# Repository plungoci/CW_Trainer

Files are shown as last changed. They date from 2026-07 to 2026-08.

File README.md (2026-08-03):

# CW Trainer

[Română](#română) · [English](#english)

<p align="center">
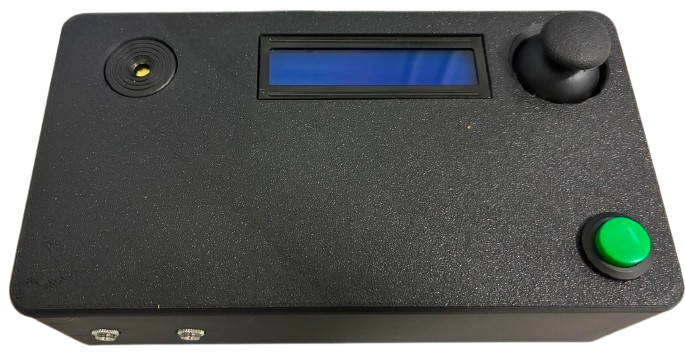
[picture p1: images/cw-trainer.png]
CW Trainer în carcasă
  
</p>

---

## Română

**CW Trainer** este un antrenor de cod Morse pentru Arduino Nano (ATmega328P).
Folosește un LCD I²C 16×2 și un buzzer activ pentru demonstrarea semnalelor,
iar pentru operare oferă butonul Morse existent, un joystick KY-023, o intrare
pentru cheie simplă și o mufă TRS pentru paddle.

### Funcții actuale

- Meniu neblocant pentru alegerea exercițiului și reglarea vitezei între **5 și
  50 WPM** (implicit 15 WPM).
- Trei tipuri de exerciții: **Litere** (`A`–`Z`), **Cifre** (`0`–`9`) și
  **Fraze** (`CQ CQ`, `TEST ONE`, `HELLO WORLD`, `73 DE YO6LPG`).
- Redare Morse fără `delay()` pentru demonstrație și paddle, cu temporizare
  standard: punct `1200 / WPM`, linie 3 puncte, spațiu între elemente 1 punct,
  între litere 3 puncte și între cuvinte 7 puncte.
- Feedback pe LCD pentru răspuns: ținta (`T:`), următorul semnal între `[]`,
  `GRESIT! Incearca`, `CORECT!` și expirarea timpului. `/` separă literele,
  iar `//` separă cuvintele.
- Cheia originală de pe D7 pornește antrenamentul din meniul principal și
  introduce puncte/linii în timpul răspunsului. O apăsare sub două unități de
  timp este punct; una mai lungă este linie.
- Cheie simplă cu sidetone imediat și keyer simplu pentru paddle. Când DIT și
  DAH sunt apăsate simultan, următorul element alternează; modurile iambic A/B
  și memoria paddlelor nu sunt implementate.

### Componente

| Cantitate | Componentă | Observații |
| ---: | --- | --- |
| 1 | Arduino Nano compatibil, ATmega328P, USB-C | Alimentare și control. |
| 1 | LCD 1602 I²C | Adresa implicită este `0x27`; încearcă `0x3F` dacă nu răspunde. |
| 1 | Buzzer piezoelectric activ | Conectat la D8 și GND. |
| 1 | Buton momentan normal deschis | Cheia Morse originală, conectată la D7 și GND. |
| 1 | Joystick KY-023 | Navigare în meniu și selectare. |
| 1 | Jack pentru cheie simplă | Semnal la D3, masă la GND. |
| 1 | Jack TRS pentru paddle | Tip = DIT, Ring = DAH, Sleeve = GND. |
| – | Fire, carcasă și elemente de fixare | După necesități. |

Toate intrările de cheie folosesc `INPUT_PULLUP`; fiecare contact se leagă la
GND când este apăsat. Nu este necesară o rezistență externă de pull-up.

### Conexiuni

| Semnal | Pin Nano | Configurație |
| --- | --- | --- |
| LCD VCC / GND | 5V / GND | Masă comună. |
| LCD SDA / SCL | A4 / A5 | Magistrala I²C. |
| Buzzer activ | D8 / GND | Ieșire digitală. |
| Buton / cheie existentă | D7 / GND | `INPUT_PULLUP`, activ LOW. |
| KY-023 axa verticală / orizontală | A0 / A1 | Intrări ADC pe 10 biți. |
| KY-023 SW | D2 | `INPUT_PULLUP`, activ LOW. |
| Cheie simplă | D3 / GND | `INPUT_PULLUP`, activ LOW. |
| Paddle DIT (Tip) | D5 | `INPUT_PULLUP`, activ LOW. |
| Paddle DAH (Ring) | D4 | `INPUT_PULLUP`, activ LOW. |
| Paddle masă (Sleeve) | GND |  |

Pentru montajul calibrat, A0 este sus la valori `>700` și jos la `<300`, iar
A1 este dreapta la `>700` și stânga la `<300`. Direcțiile pot diferi de
etichetele VRx/VRy ale joystickului; pragurile sunt centralizate în schiță.
Alimentează KY-023 la 5 V numai cu acest Nano de 5 V. Pentru o placă cu ADC de
3,3 V, folosește niveluri sigure pentru intrări.

### Utilizare

1. La pornire, LCD-ul afișează `CW Trainer` și `YO6LPG` timp de două secunde.
2. În meniul principal, mișcă joystickul **stânga/dreapta** între `Training`,
   `Viteza WPM`, `Start Training` și `Inapoi`. Apăsarea scurtă a lui SW
   confirmă elementul selectat.
3. În `Training`, alege Litere, Cifre sau Fraze și apasă scurt SW pentru a
   salva. O apăsare lungă SW revine fără salvare.
4. În `Viteza WPM`, dreapta crește și stânga scade WPM; sus/jos nu schimbă
   viteza. O apăsare scurtă sau lungă SW revine în meniu.
5. Alege `Start Training` sau apasă butonul D7 din meniul principal. Dispozitivul
   afișează ținta, redă codul, apoi așteaptă răspunsul pe D7. Dacă răspunsul nu
   începe în 10 secunde, runda expiră; după rezultat, următoarea rundă pornește
   automat după trei secunde.
6. O apăsare lungă SW în timpul antrenamentului oprește runda și revine în
   meniul principal.

<p align="center">
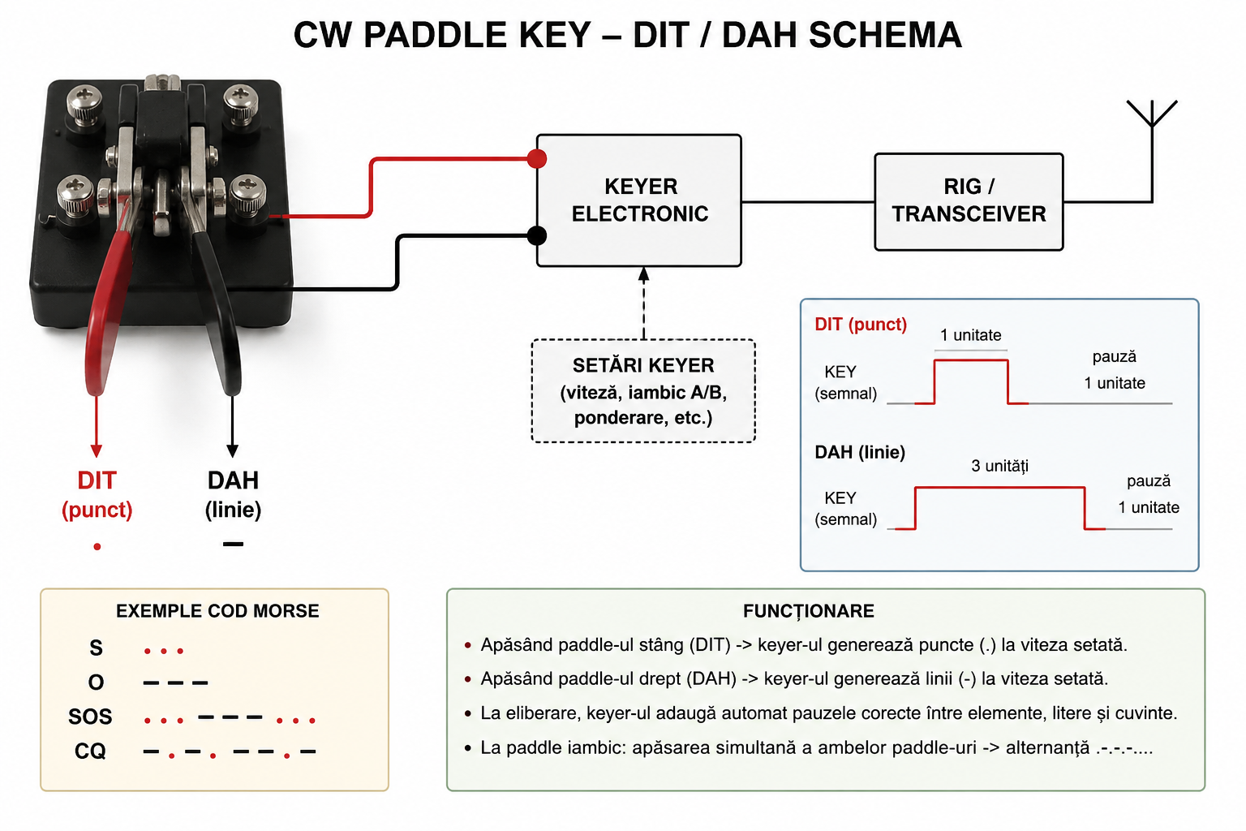
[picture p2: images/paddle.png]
Descriere paddle
   
</p>

### Instalare și diagnosticare

1. Instalează [Arduino IDE](https://www.arduino.cc/en/software) și biblioteca
   **LiquidCrystal I2C** din Library Manager. `Wire` este inclusă în IDE.
2. Deschide `cw_trainer.ino`, selectează placa Arduino Nano și portul serial,
   apoi compilează și încarcă schița.
3. Pentru calibrarea joystickului, deschide Serial Monitor la **115200 baud**
   în ecranul `Viteza WPM`. Schița imprimă valorile A0/A1, direcția detectată
   și WPM înainte/după fiecare comandă. După calibrare, setează
   `JOYSTICK_DIAGNOSTICS` la `false` dacă nu mai dorești mesaje seriale.

### Depanare

- **LCD gol:** verifică alimentarea, contrastul și încearcă adresa `0x3F`.
- **Direcții inversate:** verifică valorile din Serial Monitor și ajustează
  pragurile sau corespondența axelor din `directionFromJoystick()`.
- **Paddle inversat:** inversează valorile `PIN_PADDLE_DIT` și
  `PIN_PADDLE_DAH`.
- **Fără sunet:** verifică polaritatea buzzerului activ și legăturile D8/GND.

---

## English

**CW Trainer** is an Arduino Nano (ATmega328P) Morse-code trainer. A 16×2 I²C
LCD and active buzzer demonstrate the signals; the existing Morse button,
KY-023 joystick, straight-key input, and TRS paddle input provide operation.

### Current features

- Non-blocking menu; speed is adjustable from **5 to 50 WPM** (15 WPM by
  default).
- **Letters** (`A`–`Z`), **Numbers** (`0`–`9`), and **Phrases** (`CQ CQ`,
  `TEST ONE`, `HELLO WORLD`, `73 DE YO6LPG`) training modes.
- Delay-free Morse playback for demonstrations and paddle output, using
  standard timing derived from `1200 / WPM`.
- LCD answer feedback, including target display, highlighted next element,
  correct/incorrect messages, and timeout. `/` marks letters and `//` words.
- D7 remains the original active-low Morse button: it starts training from the
  main menu and records dots/dashes during an answer.
- Straight-key sidetone and a simple non-iambic paddle keyer. Simultaneous DIT
  and DAH alternate the next element; paddle memory and iambic A/B are not yet
  implemented.

### Wiring and use

The hardware mapping is D8 buzzer, D7 existing key, A0/A1 joystick axes, D2
joystick switch, D3 straight key, D4 paddle DIT, and D5 paddle DAH. All key
inputs use `INPUT_PULLUP` and are active LOW; connect their other contact to
GND. LCD I²C uses A4/SDA and A5/SCL. The full wiring table and Romanian
step-by-step operating guide above are the canonical reference.

Install **LiquidCrystal I2C** through Arduino IDE's Library Manager, open
`cw_trainer.ino`, select the Arduino Nano and serial port, then compile and
upload. If the display does not respond at `0x27`, try `0x3F`. For joystick
calibration, use Serial Monitor at **115200 baud** in the WPM screen; set
`JOYSTICK_DIAGNOSTICS` to `false` once calibration is complete.

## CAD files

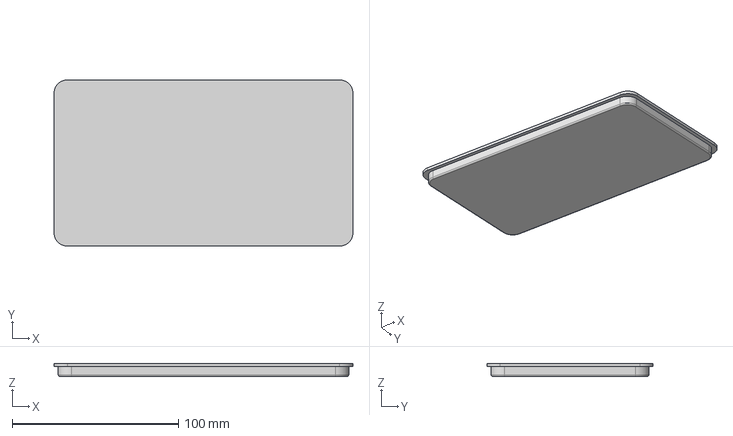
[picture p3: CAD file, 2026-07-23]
3D Model/CW-Trainer Lid.step
180.0 x 100.0 x 8.00 mm

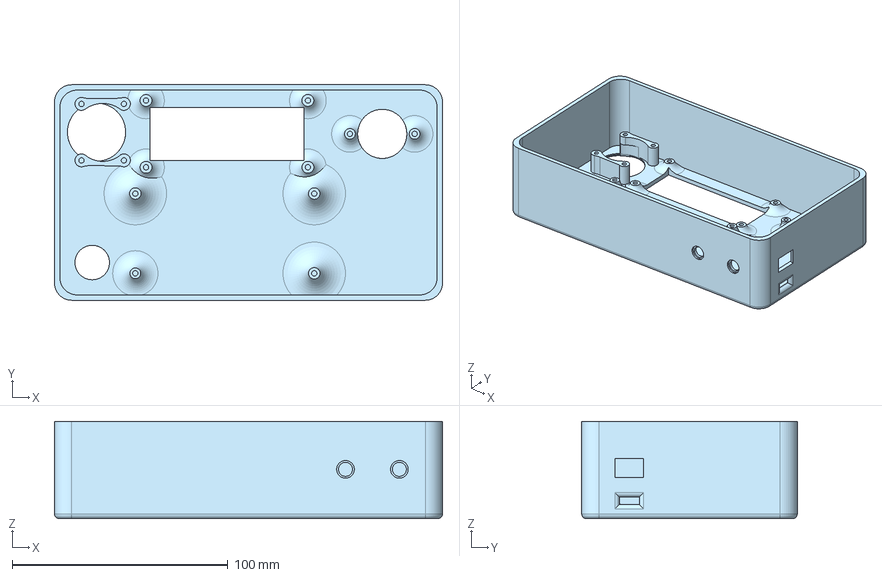
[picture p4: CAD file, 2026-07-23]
3D Model/CW-Trainer Box.step
180.0 x 100.0 x 45.0 mm

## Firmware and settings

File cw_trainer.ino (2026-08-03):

#include <Wire.h>
#include <LiquidCrystal_I2C.h>
#include <string.h>
#include <stdio.h>

// LCD 1602 I2C existent; incearca 0x3F daca modulul nu raspunde la 0x27.
LiquidCrystal_I2C lcd(0x27, 16, 2);

// Arduino Nano (ATmega328P): A4/A5 sunt rezervati pentru LCD/I2C, iar D8
// pentru buzzer. D7 este cheia/butonul original si nu este reutilizat.
constexpr byte buzzerPin = 8;
constexpr byte keyPin = 7;  // Buton existent, activ LOW, INPUT_PULLUP.
// Calibrarea pe dispozitiv a aratat ca orientarea fizica nu corespunde
// etichetelor VRx/VRy: A0 se modifica sus/jos, iar A1 stanga/dreapta.
constexpr byte PIN_JOYSTICK_AXIS_1 = A0;
constexpr byte PIN_JOYSTICK_AXIS_2 = A1;
constexpr byte PIN_JOYSTICK_SW = 2;
constexpr byte PIN_STRAIGHT_KEY = 3;
constexpr byte PIN_PADDLE_DIT = 5;
constexpr byte PIN_PADDLE_DAH = 4;

constexpr int DEFAULT_WPM = 15;
constexpr int MIN_WPM = 5;
constexpr int MAX_WPM = 50;
constexpr int WPM_STEP = 1;
constexpr byte MAIN_MENU_ITEM_COUNT = 5;
constexpr byte TEST_MENU_ITEM_COUNT = 2;
// Nano are ADC pe 10 biti (0..1023); aceste praguri sunt usor de calibrat.
constexpr int JOYSTICK_LOW_THRESHOLD = 300;
constexpr int JOYSTICK_HIGH_THRESHOLD = 700;
// Valorile brute verificate pentru montajul curent: A0 mare = SUS, A0 mic = JOS,
// A1 mare = DREAPTA si A1 mic = STANGA. Nu deduce directia din numele VRx/VRy.
constexpr bool JOYSTICK_DIAGNOSTICS = true;
constexpr unsigned long JOYSTICK_INITIAL_REPEAT_MS = 350;
constexpr unsigned long JOYSTICK_REPEAT_MS = 140;
constexpr unsigned long JOYSTICK_DEBOUNCE_MS = 25;
constexpr unsigned long JOYSTICK_LONG_PRESS_MS = 800;
constexpr unsigned long KEY_DEBOUNCE_MS = 12;
constexpr unsigned long answerTimeout = 10000UL;

struct MorseTiming {
  unsigned long dit;
  unsigned long dah;
  unsigned long elementGap;
  unsigned long characterGap;
  unsigned long wordGap;
};

enum class TrainingMode { Letters, Numbers, Phrases };
enum class AppState { MainMenu, TrainingSelection, WpmSettings, Training, TestMenu, KeyTest, PaddleTest };
enum class JoystickEvent { None, Up, Down, Left, Right, ShortPress, LongPress };
enum class OutputPhase { Idle, Tone, Gap };
enum class TrainingPhase { Choose, Preview, Playing, WaitAnswer, Result };

int currentWpm = DEFAULT_WPM;
MorseTiming timing;
TrainingMode trainingMode = TrainingMode::Letters;
AppState appState = AppState::MainMenu;
TrainingPhase trainingPhase = TrainingPhase::Choose;
byte menuIndex = 0;
byte selectionIndex = 0;
byte testMenuIndex = 0;
bool displayDirty = true;

// Buffer comun pentru ecranele de test hardware: acumuleaza simbolurile
// tastate pentru litera curenta si textul deja decodat. Titlul ecranului
// ramane fix pe randul de sus; randul de jos arata textul decodat urmat de
// codul Morse curent, neterminat, intre paranteze drepte.
constexpr byte TEST_KEYER_TEXT_CAP = 32;
char testKeyerCode[9];
byte testKeyerCodeLength = 0;
char testKeyerText[TEST_KEYER_TEXT_CAP + 1];
byte testKeyerTextLength = 0;
unsigned long testKeyerLastSymbolAt = 0;
bool testKeyerHasPendingSymbol = false;

bool previousKeyTestDown = false;
unsigned long keyTestChangedAt = 0;
unsigned long keyTestDownAt = 0;

bool previousPaddleTestDitDown = false;
unsigned long paddleTestDitChangedAt = 0;
bool previousPaddleTestDahDown = false;
unsigned long paddleTestDahChangedAt = 0;

const char characters[] = "ABCDEFGHIJKLMNOPQRSTUVWXYZ0123456789";
const char *const morseCodes[] = {
  ".-", "-...", "-.-.", "-..", ".", "..-.", "--.", "....", "..", ".---",
  "-.-", ".-..", "--", "-.", "---", ".--.", "--.-", ".-.", "...", "-",
  "..-", "...-", ".--", "-..-", "-.--", "--..",
  "-----", ".----", "..---", "...--", "....-", ".....", "-....", "--...", "---..", "----."
};
constexpr byte LETTER_COUNT = 26;
constexpr byte CHARACTER_COUNT = sizeof(characters) - 1;
// Frazele sunt stocate in flash ca date constante; extinde lista fara RAM dinamic.
const char phrases[][17] = { "CQ CQ", "TEST ONE", "HELLO WORLD", "73 DE YO6LPG" };
constexpr byte PHRASE_COUNT = sizeof(phrases) / sizeof(phrases[0]);

// Motorul comun pentru demonstratie si paddle. Nu foloseste delay().
OutputPhase outputPhase = OutputPhase::Idle;
const char *outputCode = nullptr;
byte outputPosition = 0;
unsigned long outputDeadline = 0;
bool outputFinished = false;

char targetText[17];
char targetCode[110];
bool answerStarted = false;
bool previousExistingKeyDown = false;
unsigned long existingKeyChangedAt = 0;
unsigned long existingKeyDownAt = 0;
unsigned long answerStartedAt = 0;
unsigned long phaseStartedAt = 0;
bool answerCorrect = false;

void acceptAnswerSignal(char signal);
// Pozitia urmatorului semnal care trebuie introdus. Separatorii din targetCode
// ('/' intre litere si '|' intre cuvinte) nu necesita o apasare a cheii.
byte expectedPosition = 0;
bool answerHasError = false;
unsigned long answerErrorShownAt = 0;

bool previousStraightDown = false;
unsigned long straightChangedAt = 0;
bool paddleLastWasDit = false;

bool previousPaddleDitDown = false;
unsigned long paddleDitChangedAt = 0;
bool previousPaddleDahDown = false;
unsigned long paddleDahChangedAt = 0;

bool previousJoystickButtonDown = false;
unsigned long joystickButtonChangedAt = 0;
unsigned long joystickButtonDownAt = 0;
bool joystickLongReported = false;
JoystickEvent heldDirection = JoystickEvent::None;
unsigned long directionChangedAt = 0;
unsigned long directionRepeatAt = 0;
int lastJoystickAxis1 = 0;
int lastJoystickAxis2 = 0;

void recalculateMorseTiming() {
  timing.dit = 1200UL / currentWpm;
  timing.dah = timing.dit * 3UL;
  timing.elementGap = timing.dit;
  timing.characterGap = timing.dit * 3UL;
  timing.wordGap = timing.dit * 7UL;
}

const char *modeName(TrainingMode mode) {
  if (mode == TrainingMode::Letters) return "Litere";
  if (mode == TrainingMode::Numbers) return "Cifre";
  return "Fraze";
}

void soundOn() { digitalWrite(buzzerPin, HIGH); }
void soundOff() { digitalWrite(buzzerPin, LOW); }

void startMorseOutput(const char *code) {
  outputCode = code;
  outputPosition = 0;
  outputPhase = OutputPhase::Idle;
  outputFinished = false;
}

bool morseOutputBusy() { return outputCode != nullptr; }

void updateMorseOutput() {
  if (!outputCode) return;
  unsigned long now = millis();
  if (outputPhase == OutputPhase::Idle) {
    if (outputCode[outputPosition] == '\0') {
      outputCode = nullptr;
      outputFinished = true;
      soundOff();
      return;
    }
    // Separators are generated by buildPhraseMorse(): the normal element gap
    // has already elapsed, so add the remaining units for a character/word.
    if (outputCode[outputPosition] == '/' || outputCode[outputPosition] == '|') {
      soundOff();
      outputDeadline = now + (outputCode[outputPosition] == '/' ?
        timing.characterGap - timing.elementGap : timing.wordGap - timing.elementGap);
      outputPhase = OutputPhase::Gap;
      return;
    }
    soundOn();
    outputDeadline = now + (outputCode[outputPosition] == '.' ? timing.dit : timing.dah);
    outputPhase = OutputPhase::Tone;
  } else if (now >= outputDeadline) {
    if (outputPhase == OutputPhase::Tone) {
      soundOff();
      outputDeadline = now + timing.elementGap;
      outputPhase = OutputPhase::Gap;
    } else {
      ++outputPosition;
      outputPhase = OutputPhase::Idle;
    }
  }
}

const char *morseForCharacter(char character) {
  if (character >= 'A' && character <= 'Z') return morseCodes[character - 'A'];
  if (character >= '0' && character <= '9') return morseCodes[LETTER_COUNT + character - '0'];
  return nullptr;
}

void buildPhraseMorse(const char *phrase, char *destination, size_t destinationSize) {
  size_t used = 0;
  for (byte i = 0; phrase[i] != '\0' && used + 1 < destinationSize; ++i) {
    if (phrase[i] == ' ') {
      destination[used++] = '|';
      continue;
    }
    const char *code = morseForCharacter(phrase[i]);
    if (!code) continue;
    for (byte j = 0; code[j] != '\0' && used + 1 < destinationSize; ++j) destination[used++] = code[j];
    if (phrase[i + 1] != '\0' && phrase[i + 1] != ' ' && used + 1 < destinationSize) destination[used++] = '/';
  }
  destination[used] = '\0';
}

JoystickEvent directionFromJoystick() {
  // Citeste ambele canale o singura data, pentru ca diagnosticul si decodorul
  // sa descrie exact aceeasi pozitie a manetei.
  lastJoystickAxis1 = analogRead(PIN_JOYSTICK_AXIS_1);
  lastJoystickAxis2 = analogRead(PIN_JOYSTICK_AXIS_2);

  // A0 este axa fizica verticala in acest montaj; ea nu ajunge la adjustWpm().
  if (lastJoystickAxis1 > JOYSTICK_HIGH_THRESHOLD) return JoystickEvent::Up;
  if (lastJoystickAxis1 < JOYSTICK_LOW_THRESHOLD) return JoystickEvent::Down;
  // A1 este axa fizica orizontala. Valoarea mare este dreapta fizica.
  if (lastJoystickAxis2 < JOYSTICK_LOW_THRESHOLD) return JoystickEvent::Left;
  if (lastJoystickAxis2 > JOYSTICK_HIGH_THRESHOLD) return JoystickEvent::Right;
  return JoystickEvent::None;
}

const char *joystickEventName(JoystickEvent event) {
  switch (event) {
    case JoystickEvent::Up: return "UP";
    case JoystickEvent::Down: return "DOWN";
    case JoystickEvent::Left: return "LEFT";
    case JoystickEvent::Right: return "RIGHT";
    default: return "NONE";
  }
}

void logWpmJoystickDiagnostic(JoystickEvent event, int wpmBefore, int wpmAfter) {
  if (!JOYSTICK_DIAGNOSTICS) return;
  Serial.print(F("Joystick raw: axis1=")); Serial.print(lastJoystickAxis1);
  Serial.print(F(", axis2=")); Serial.println(lastJoystickAxis2);
  Serial.print(F("Detected physical direction: ")); Serial.println(joystickEventName(event));
  Serial.print(F("WPM before: ")); Serial.println(wpmBefore);
  Serial.print(F("WPM after: ")); Serial.println(wpmAfter);
}

JoystickEvent updateJoystick() {
  unsigned long now = millis();
  bool down = digitalRead(PIN_JOYSTICK_SW) == LOW;
  if (down != previousJoystickButtonDown && now - joystickButtonChangedAt >= JOYSTICK_DEBOUNCE_MS) {
    previousJoystickButtonDown = down;
    joystickButtonChangedAt = now;
    if (down) { joystickButtonDownAt = now; joystickLongReported = false; }
    else if (!joystickLongReported) return JoystickEvent::ShortPress;
  }
  if (down && !joystickLongReported && now - joystickButtonDownAt >= JOYSTICK_LONG_PRESS_MS) {
    joystickLongReported = true;
    return JoystickEvent::LongPress;
  }
  JoystickEvent direction = directionFromJoystick();
  if (direction != heldDirection) {
    heldDirection = direction;
    directionChangedAt = now;
    directionRepeatAt = now + JOYSTICK_INITIAL_REPEAT_MS;
    return direction;
  }
  if (direction != JoystickEvent::None && now >= directionRepeatAt) {
    directionRepeatAt = now + JOYSTICK_REPEAT_MS;
    return direction;
  }
  return JoystickEvent::None;
}

void printPadded(const char *line) {
  lcd.print(line);
  byte length = strlen(line);
  while (length++ < 16) lcd.print(' ');
}

void renderMenu() {
  if (!displayDirty) return;
  lcd.clear();
  if (appState == AppState::MainMenu) {
    const char *items[] = { "Training", "Viteza WPM", "Start Training", "Test Hardware", "Inapoi" };
    lcd.setCursor(0, 0); lcd.print('>'); lcd.print(items[menuIndex]);
    lcd.setCursor(0, 1);
    if (menuIndex == 0) { lcd.print(modeName(trainingMode)); }
    else if (menuIndex == 1) { lcd.print(currentWpm); lcd.print(" WPM"); }
    else if (menuIndex == 2) lcd.print("Buton D7 = start");
    else if (menuIndex == 3) lcd.print("Cheie / Paddle");
    else lcd.print("Apasa lung: sus");
  } else if (appState == AppState::TrainingSelection) {
    lcd.setCursor(0, 0); lcd.print("Training:");
    lcd.setCursor(0, 1); lcd.print('>'); lcd.print(modeName(static_cast<TrainingMode>(selectionIndex)));
  } else if (appState == AppState::WpmSettings) {
    lcd.setCursor(0, 0); lcd.print("Viteza WPM");
    lcd.setCursor(0, 1); lcd.print("< "); lcd.print(currentWpm); lcd.print(" WPM >");
  } else if (appState == AppState::TestMenu) {
    const char *testItems[] = { "Test Cheie CW", "Test Paddle CW" };
    lcd.setCursor(0, 0); lcd.print("Test Hardware:");
    lcd.setCursor(0, 1); lcd.print('>'); lcd.print(testItems[testMenuIndex]);
  }
  displayDirty = false;
}

void startTraining() {
  appState = AppState::Training;
  trainingPhase = TrainingPhase::Choose;
  outputCode = nullptr;
  soundOff();
  displayDirty = true;
}

void adjustWpm(JoystickEvent event) {
  int requestedWpm = currentWpm;
  // Reglarea vitezei accepta exclusiv evenimentele produse de axa orizontala.
  // Up si Down nu pot modifica WPM in acest ecran.
  switch (event) {
    case JoystickEvent::Right:
      requestedWpm += WPM_STEP;
      break;
    case JoystickEvent::Left:
      requestedWpm -= WPM_STEP;
      break;
    default:
      return;
  }

  // Clamp the requested speed so a changed step size can never cross a limit.
  requestedWpm = constrain(requestedWpm, MIN_WPM, MAX_WPM);
  if (requestedWpm == currentWpm) return;

  currentWpm = requestedWpm;
  recalculateMorseTiming();
  displayDirty = true;
}

void updateMenu(JoystickEvent event) {
  if (appState == AppState::Training || appState == AppState::KeyTest || appState == AppState::PaddleTest) return;
  if (appState == AppState::MainMenu) {
    // Meniul principal se parcurge exclusiv pe axa orizontala: dreapta pentru
    // urmatorul element si stanga pentru cel anterior. Butonul SW confirma
    // elementul afisat, astfel incat dreapta nu poate deschide accidental un
    // ecran de setari.
    if (event == JoystickEvent::Left && menuIndex > 0) { --menuIndex; displayDirty = true; }
    if (event == JoystickEvent::Right && menuIndex < MAIN_MENU_ITEM_COUNT - 1) { ++menuIndex; displayDirty = true; }
    if (event == JoystickEvent::ShortPress) {
      if (menuIndex == 0) { appState = AppState::TrainingSelection; selectionIndex = static_cast<byte>(trainingMode); displayDirty = true; }
      else if (menuIndex == 1) { appState = AppState::WpmSettings; displayDirty = true; }
      else if (menuIndex == 2) startTraining();
      else if (menuIndex == 3) { appState = AppState::TestMenu; testMenuIndex = 0; displayDirty = true; }
    }
  } else if (appState == AppState::TestMenu) {
    if ((event == JoystickEvent::Up || event == JoystickEvent::Left) && testMenuIndex > 0) { --testMenuIndex; displayDirty = true; }
    if ((event == JoystickEvent::Down || event == JoystickEvent::Right) && testMenuIndex < TEST_MENU_ITEM_COUNT - 1) { ++testMenuIndex; displayDirty = true; }
    if (event == JoystickEvent::ShortPress) {
      if (testMenuIndex == 0) enterKeyTest(); else enterPaddleTest();
    }
    if (event == JoystickEvent::LongPress) { appState = AppState::MainMenu; displayDirty = true; }
  } else if (appState == AppState::TrainingSelection) {
    if ((event == JoystickEvent::Up || event == JoystickEvent::Left) && selectionIndex > 0) { --selectionIndex; displayDirty = true; }
    if ((event == JoystickEvent::Down || event == JoystickEvent::Right) && selectionIndex < 2) { ++selectionIndex; displayDirty = true; }
    if (event == JoystickEvent::ShortPress) { trainingMode = static_cast<TrainingMode>(selectionIndex); appState = AppState::MainMenu; displayDirty = true; }
    if (event == JoystickEvent::LongPress) { appState = AppState::MainMenu; displayDirty = true; }
  } else if (appState == AppState::WpmSettings) {
    // In setarile WPM, doar directia orizontala modifica viteza:
    // dreapta creste, iar stanga scade.
    int wpmBefore = currentWpm;
    adjustWpm(event);
    if (event == JoystickEvent::Up || event == JoystickEvent::Down ||
        event == JoystickEvent::Left || event == JoystickEvent::Right) {
      logWpmJoystickDiagnostic(event, wpmBefore, currentWpm);
    }
    if (event == JoystickEvent::ShortPress || event == JoystickEvent::LongPress) { appState = AppState::MainMenu; displayDirty = true; }
  }
}

// D7 pastreaza semantica originala: LOW inseamna apasat, tine sidetone-ul
// activ pe durata apasarii si masoara punct/linie in timpul raspunsului.
void updateExistingKeyButton() {
  unsigned long now = millis();
  bool down = digitalRead(keyPin) == LOW;
  if (down != previousExistingKeyDown && now - existingKeyChangedAt >= KEY_DEBOUNCE_MS) {
    previousExistingKeyDown = down;
    existingKeyChangedAt = now;
    if (down) {
      existingKeyDownAt = now;
      if (appState == AppState::MainMenu) startTraining();
      if (appState == AppState::Training && trainingPhase == TrainingPhase::WaitAnswer) {
        answerStarted = true;
        soundOn();
      }
    } else if (appState == AppState::Training && trainingPhase == TrainingPhase::WaitAnswer) {
      soundOff();
      unsigned long pressDuration = now - existingKeyDownAt;
      if (pressDuration >= 15) acceptAnswerSignal(pressDuration < timing.dit * 2UL ? '.' : '-');
    }
  }
}

// Straight key este independent de D7 si are sidetone imediat, cu filtrare scurta.
void updateStraightKey() {
  if (appState == AppState::KeyTest) return;  // sidetone-ul e gestionat de updateKeyTest().
  unsigned long now = millis();
  bool down = digitalRead(PIN_STRAIGHT_KEY) == LOW;
  if (down != previousStraightDown && now - straightChangedAt >= KEY_DEBOUNCE_MS) {
    previousStraightDown = down;
    straightChangedAt = now;
    if (appState != AppState::Training || trainingPhase != TrainingPhase::WaitAnswer) {
      if (down) soundOn(); else if (!morseOutputBusy()) soundOff();
    }
  }
}

// In faza de raspuns, padela are contacte separate pentru punct/linie, deci
// fiecare parghie trimite direct simbolul ei (spre deosebire de D7, care
// masoara durata apasarii). Sidetone-ul tine cat parghia este apasata.
void updatePaddleAnswer() {
  unsigned long now = millis();
  bool ditDown = digitalRead(PIN_PADDLE_DIT) == LOW;
  if (ditDown != previousPaddleDitDown && now - paddleDitChangedAt >= KEY_DEBOUNCE_MS) {
    previousPaddleDitDown = ditDown;
    paddleDitChangedAt = now;
    if (ditDown) { answerStarted = true; soundOn(); }
    else { soundOff(); acceptAnswerSignal('.'); }
  }
  bool dahDown = digitalRead(PIN_PADDLE_DAH) == LOW;
  if (dahDown != previousPaddleDahDown && now - paddleDahChangedAt >= KEY_DEBOUNCE_MS) {
    previousPaddleDahDown = dahDown;
    paddleDahChangedAt = now;
    if (dahDown) { answerStarted = true; soundOn(); }
    else { soundOff(); acceptAnswerSignal('-'); }
  }
}

// Keyer simplu non-iambic: la ambele padele selecteaza alternativ DIT/DAH.
// Este delimitat aici pentru extindere ulterioara cu memoria padelelor/Mode A/B.
void updatePaddle() {
  if (appState == AppState::PaddleTest) return;  // sidetone-ul e gestionat de updatePaddleTest().
  if (appState == AppState::Training && trainingPhase == TrainingPhase::WaitAnswer) {
    updatePaddleAnswer();
    return;
  }
  if (morseOutputBusy()) return;
  bool dit = digitalRead(PIN_PADDLE_DIT) == LOW;
  bool dah = digitalRead(PIN_PADDLE_DAH) == LOW;
  if (!dit && !dah) return;
  bool sendDit = dit;
  if (dit && dah) sendDit = paddleLastWasDit ? false : true;
  else if (dah) sendDit = false;
  paddleLastWasDit = sendDit;
  startMorseOutput(sendDit ? "." : "-");
}

void chooseTrainingTarget() {
  if (trainingMode == TrainingMode::Phrases) {
    strncpy(targetText, phrases[random(PHRASE_COUNT)], sizeof(targetText));
    targetText[sizeof(targetText) - 1] = '\0';
    buildPhraseMorse(targetText, targetCode, sizeof(targetCode));
  } else {
    byte first = trainingMode == TrainingMode::Letters ? 0 : LETTER_COUNT;
    byte count = trainingMode == TrainingMode::Letters ? LETTER_COUNT : CHARACTER_COUNT - LETTER_COUNT;
    byte index = first + random(count);
    targetText[0] = characters[index]; targetText[1] = '\0';
    strncpy(targetCode, morseCodes[index], sizeof(targetCode));
  }
}

void showTrainingLine(const char *top, const char *bottom) {
  lcd.clear(); lcd.setCursor(0, 0); printPadded(top); lcd.setCursor(0, 1); printPadded(bottom);
}

// Ecrane de diagnostic hardware: afiseaza in timp real ce se tasteaza, atat
// pentru cheia simpla cat si pentru padele. Sidetone-ul ramane cel produs
// direct aici (nu de updateStraightKey()/updatePaddle(), care raman blocate
// in aceste stari ca sa nu porneasca si motorul automat de morse).
// Randul de sus ramane titlul fix al ecranului, ca sa fie clar ca s-a
// intrat intr-o pagina noua. Randul de jos arata textul deja decodat, urmat
// de codul Morse curent (inca neterminat) intre paranteze drepte; cand
// depaseste 16 coloane, se afiseaza doar coada, cea mai recenta parte.
char decodeMorseSymbol(const char *code) {
  for (byte i = 0; i < CHARACTER_COUNT; ++i) {
    if (strcmp(morseCodes[i], code) == 0) return characters[i];
  }
  return '?';
}

void resetTestKeyer() {
  testKeyerCode[0] = '\0';
  testKeyerCodeLength = 0;
  testKeyerText[0] = '\0';
  testKeyerTextLength = 0;
  testKeyerHasPendingSymbol = false;
}

void renderTestKeyerLine() {
  char combined[TEST_KEYER_TEXT_CAP + sizeof(testKeyerCode) + 2];
  if (testKeyerCodeLength > 0) {
    snprintf(combined, sizeof(combined), "%s[%s]", testKeyerText, testKeyerCode);
  } else {
    snprintf(combined, sizeof(combined), "%s", testKeyerText);
  }
  size_t length = strlen(combined);
  const char *tail = length > 16 ? combined + (length - 16) : combined;
  lcd.setCursor(0, 1);
  printPadded(tail);
}
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
void loop() {
  JoystickEvent event = updateJoystick();
  updateExistingKeyButton();
  updateStraightKey();
  updatePaddle();
  AppState stateBeforeMenu = appState;
  updateMenu(event);
  // Daca updateMenu() tocmai a schimbat ecranul (ex: ShortPress a deschis
  // Test Cheie CW din submeniu), acelasi eveniment nu se mai transmite mai
  // departe: altfel ecranul nou l-ar citi imediat ca semnal de iesire, in
  // aceeasi bucla in care tocmai a fost deschis.
  JoystickEvent activeScreenEvent = (appState != stateBeforeMenu) ? JoystickEvent::None : event;
  updateTraining(activeScreenEvent);
  updateKeyTest(activeScreenEvent);
  updatePaddleTest(activeScreenEvent);
  updateMorseOutput();
  renderMenu();
}

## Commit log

2026-07-17 Add CW Trainer documentation and BOM
2026-07-19 Add M3 screws to BOM
2026-07-20 feat: require button press to start test
2026-07-23 Fix WPM joystick direction controls
    [cw_trainer.ino]
2026-07-23 Clamp WPM joystick adjustments
2026-07-23 Fix WPM control for calibrated joystick axes
    [cw_trainer.ino]
2026-07-23 Fix horizontal joystick menu navigation
    [cw_trainer.ino]
2026-07-23 Update README for current trainer features
2026-08-03 Add hardware test submenu for straight key and paddle
    Adds a "Test Hardware" entry to the main menu with two child screens
    that show live press state on the LCD (Test Cheie CW for D3, Test
    Paddle CW for D4/D5), useful for verifying wiring without leaving the
    device.
    Claude-Session: https://claude.ai/code/session_017sB5urXdg7hv8VafZuGhxu
2026-08-03 Fix paddle key not responding during training answer phase
    updatePaddle() short-circuited entirely while TrainingPhase::WaitAnswer
    was active, so the CW paddle produced no sidetone and never submitted
    an answer. Added updatePaddleAnswer(), which lets each lever (dit/dah)
    submit its own symbol directly on release, since a paddle has separate
    contacts per symbol unlike the timing-based D7 button.
    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
    [cw_trainer.ino]
2026-08-03 Show live Morse being keyed in the hardware test screens
    Test Cheie CW and Test Paddle CW previously only showed a static
    press/release state, which didn't let you verify the actual dots and
    dashes you were sending. Both screens now build up the raw Morse code
    of the current letter on the bottom row and decode it into scrolling
    text on the top row once a character gap elapses, so you can read back
    exactly what you typed.
    Straight key duration classifies dot/dash like the existing D7 button;
    paddle levers map directly to their symbol since they have separate
    contacts. updateStraightKey()/updatePaddle() now skip their own
    sidetone handling while a test screen owns the same pin, avoiding two
    i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
    [cw_trainer.ino]
2026-08-03 Keep a fixed title on the hardware test screens
    Test Cheie CW / Test Paddle CW previously started completely blank
    until the first keystroke, which didn't clearly signal that a new
    screen had opened. The title now stays fixed on the top row for the
    whole session; the bottom row shows the decoded text followed by the
    in-progress raw code in brackets, windowed to the last 16 columns.
    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
    [cw_trainer.ino]
2026-08-03 Fix Test Cheie CW / Test Paddle CW bouncing back instantly on entry
    The joystick ShortPress that opens a test screen from the submenu was
    being processed twice in the same loop() tick: once by updateMenu(),
    which switched appState to KeyTest/PaddleTest, and again immediately
    after by updateKeyTest()/updatePaddleTest(), which treat ShortPress as
    the signal to exit back to the submenu. The screen never actually
    stayed open - it bounced back before the next frame.
    loop() now suppresses the triggering event for the newly active screen
    whenever updateMenu() changes appState during that tick, so entry and
    exit can no longer be triggered by the same physical click.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
    [cw_trainer.ino]
